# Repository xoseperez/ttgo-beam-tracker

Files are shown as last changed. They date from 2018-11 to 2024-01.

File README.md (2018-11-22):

# TTN Tracker

This is a LoRaWAN node based on the TTGO T-Beam development platform.
It uses a RFM95 by HopeRF and the MCCI LoRaWAN LMIC stack.
The sample code is configured to connect to The Things Network using EU frequency, but you can easily change that.






This repository contains:

* 3D model of the enclosure, both OpenSCAD and STL files.
* Sample code that sends GPS data compatible with [TTNMapper](http://ttnmapper.org).
* Javascript decoder code to decode payload

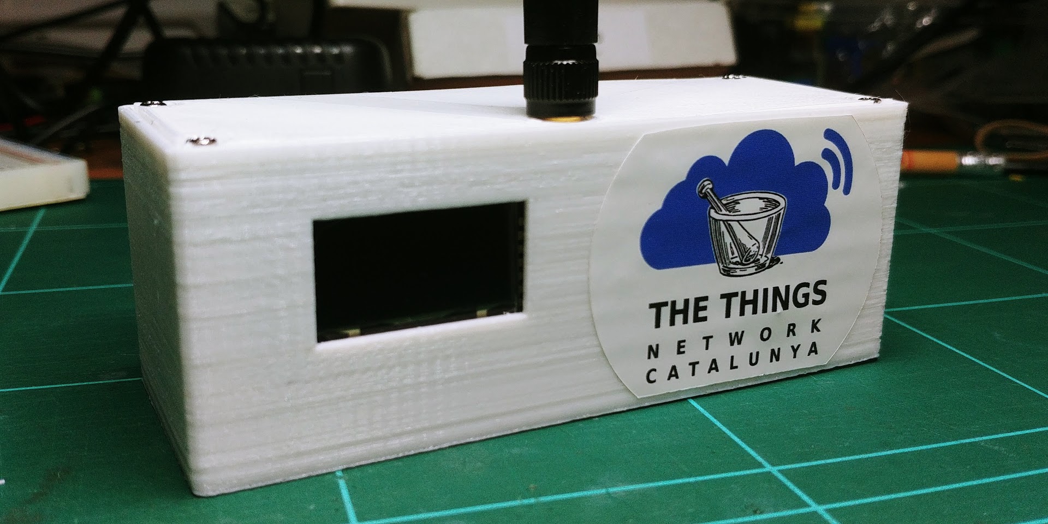
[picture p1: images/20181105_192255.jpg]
Device


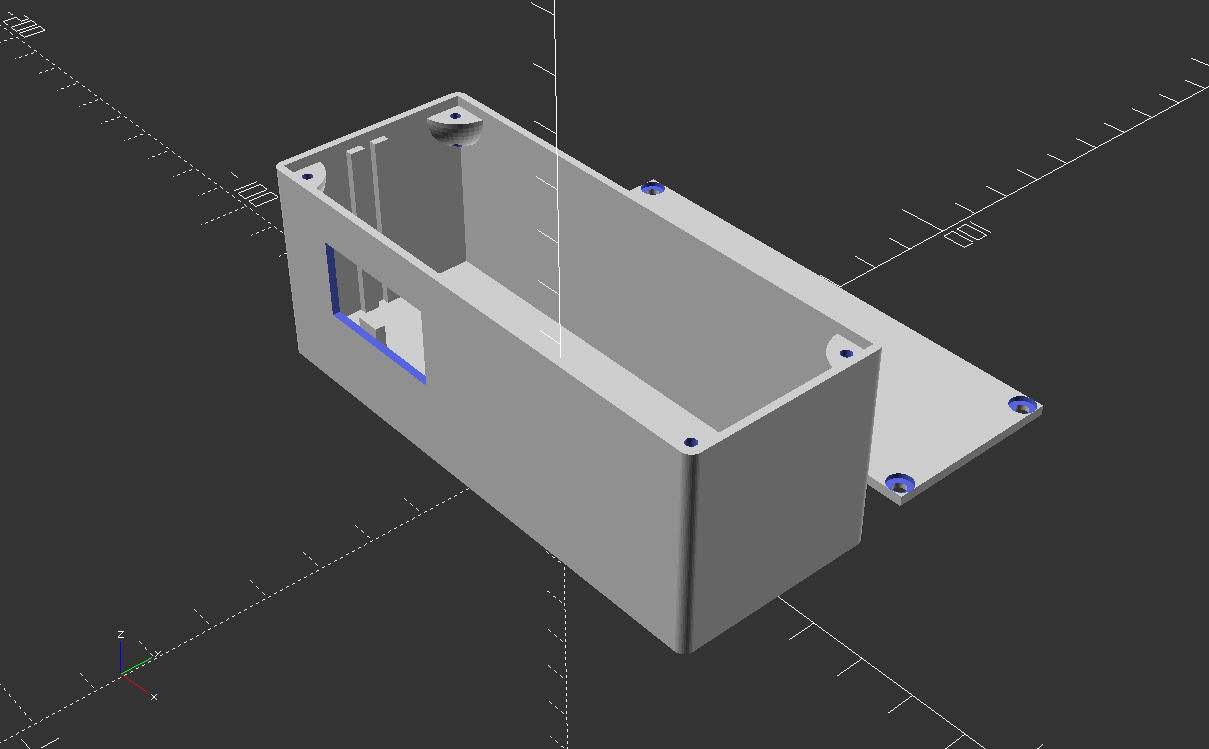
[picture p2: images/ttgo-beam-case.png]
Design


## License

Copyright (C) 2018 by Xose Pérez (@xoseperez)

This program is free software: you can redistribute it and/or modify
it under the terms of the GNU General Public License as published by
the Free Software Foundation, either version 3 of the License, or
(at your option) any later version.

This program is distributed in the hope that it will be useful,
but WITHOUT ANY WARRANTY; without even the implied warranty of
MERCHANTABILITY or FITNESS FOR A PARTICULAR PURPOSE.  See the
GNU General Public License for more details.

You should have received a copy of the GNU General Public License
along with this program.  If not, see <http://www.gnu.org/licenses/>.

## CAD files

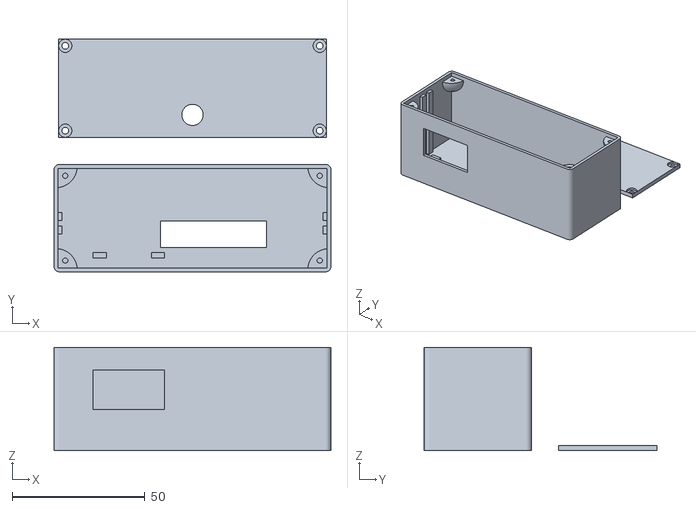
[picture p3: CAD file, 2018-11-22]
enclosure/ttgo-beam.stl
104.5 x 87.7 x 39.0

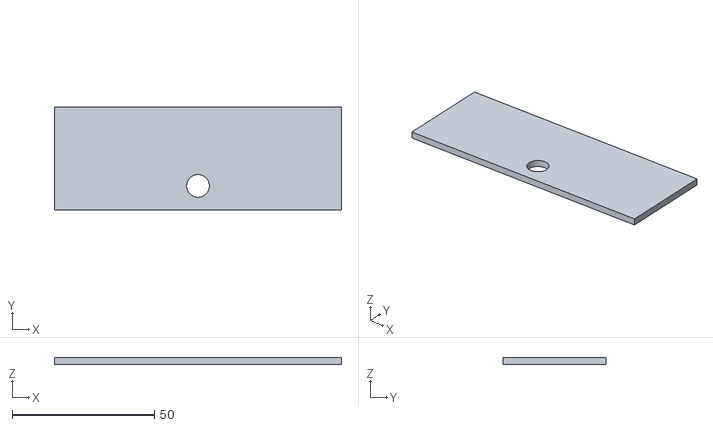
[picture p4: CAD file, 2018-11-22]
enclosure/ttgo-beam-lid.stl
101.0 x 36.3 x 2.50

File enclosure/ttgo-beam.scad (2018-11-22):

// -------------------------------------------------
// Settings
// -------------------------------------------------

$fn = 50;

// -------------------------------------------------
// Configuration
// -------------------------------------------------

device_width = 100.0;
device_depth = 36.0;
device_height = 34.0;
wall_thickness = 3.0;
board_thickness = 2.1;
device_front_depth = 16.0;
rack_depth = 3.0;
corner_radius = 8.0;
screw_length = 12.0;
screw_head = 2.5;
screw_offset = 3.5; // was 2.5
display_left = 12.5;
display_bottom = 12.5;
display_width = 27.0;
display_inner_width = 17.0;
display_height = 15.0;
display_guide = 4.0;
antenna_radius = 4.0;
antenna_y = -7;
xamfra = 2;

// -------------------------------------------------

board_y = -device_depth/2 + device_front_depth - board_thickness / 2;
box_width = device_width + wall_thickness;
box_depth = device_depth + wall_thickness;
box_height = device_height + wall_thickness;

// -------------------------------------------------
// Modules
// -------------------------------------------------

module base() {
    linear_extrude(wall_thickness) {
        difference() {
            minkowski() {
                square([box_width-2*xamfra, box_depth-2*xamfra], true);
                circle(xamfra, true);
            }
            translate([8, board_y-3]) square([40,10], true);
        }
    }
}

module lid() {
    difference() {
        linear_extrude(wall_thickness-1) {
            difference() {
                square([box_width-wall_thickness/2-0.5,box_depth-wall_thickness/2-0.5], true);
                translate([0, board_y + antenna_y]) circle(antenna_radius, true);
                translate([box_width/2-screw_offset, box_depth/2-screw_offset ]) circle(screw_head/2,true);
                translate([box_width/2-screw_offset, -box_depth/2+screw_offset ]) circle(screw_head/2,true);
                translate([-box_width/2+screw_offset, box_depth/2-screw_offset ]) circle(screw_head/2,true);
                translate([-box_width/2+screw_offset, -box_depth/2+screw_offset ]) circle(screw_head/2,true);
            }
        }
        translate([0,0,1]) linear_extrude(10) {
                translate([box_width/2-screw_offset, box_depth/2-screw_offset ]) circle(screw_head,true);
                translate([box_width/2-screw_offset, -box_depth/2+screw_offset ]) circle(screw_head,true);
                translate([-box_width/2+screw_offset, box_depth/2-screw_offset ]) circle(screw_head,true);
                translate([-box_width/2+screw_offset, -box_depth/2+screw_offset ]) circle(screw_head,true);

        }
    }
}

module walls() {
    difference() {
        union() {
            linear_extrude(box_height + wall_thickness - 1) {
                difference() {
                    minkowski() {
                        square([box_width+wall_thickness/2-2*xamfra,box_depth+wall_thickness/2-2*xamfra], true);
                        circle(xamfra, true);
                    }
                    square([box_width-wall_thickness/2,box_depth-wall_thickness/2], true);
                }
            }
            translate([
                -box_width/2+wall_thickness/2+display_left+display_width/2,
                -(box_depth-wall_thickness)/2+display_guide
            ]) linear_extrude(display_bottom) {
                difference() {
                    square([display_width, 2], true);
                    square([display_inner_width, 2], true);
                }
            }
        }
        translate([
            -box_width/2+wall_thickness/2+display_left+display_width/2,
            -(box_depth-wall_thickness)/2,
            display_bottom+display_height/2+wall_thickness
        ]) display();
    }
}

module rack() {
    linear_extrude(box_height) {
        translate([0,board_y+board_thickness/2]) 
            union() {
                translate([(box_width-wall_thickness)/2,
                    (board_thickness+rack_depth)/2]) {
                    square([rack_depth/2,rack_depth], true);
                }
                translate([(box_width-wall_thickness)/2,
                    -(board_thickness+rack_depth)/2]) {
                    square([rack_depth/2,rack_depth], true);
                }
                translate([-(box_width-wall_thickness)/2,
                    (board_thickness+rack_depth)/2]) {
                    square([rack_depth/2,rack_depth], true);
                }
                translate([-(box_width-wall_thickness)/2,
                    -(board_thickness+rack_depth)/2]) {
                    square([rack_depth/2,rack_depth], true);
                }
            }
    }
}

module corners() {
    union() {
        translate([-box_width/2,-box_depth/2,box_height]) corner();
        translate([box_width/2,-box_depth/2,box_height]) rotate([0,0,90]) corner();
        translate([box_width/2,box_depth/2,box_height]) rotate([0,0,180]) corner();
        translate([-box_width/2,box_depth/2,box_height]) rotate([0,0,270]) corner();
    }
}

module corner() {
    difference() {
        intersection() {
            sphere(corner_radius, true);
            translate([0,0,-corner_radius]) cube(corner_radius);
        }
        translate([screw_offset,screw_offset,-screw_length]) linear_extrude(screw_length) {
            circle([screw_head/2],true);
        }
    }
}

module display() {
    rotate([90,0,0])
        linear_extrude(wall_thickness)
            square([display_width, display_height], true);
}

module device() {
    rotate([90,0,0]) linear_extrude(1.6) square([device_width, device_height], true);
}

// -------------------------------------------------
// Entry points
// -------------------------------------------------

module full() {
    union() {
        base();
        walls();
        rack();
        corners();
    }
}

full();
//translate([0,0,box_height + 10]) lid();
translate([0,box_depth + 10,0]) lid();
//translate([0,board_y+wall_thickness/2,wall_thickness + device_height/2]) device();

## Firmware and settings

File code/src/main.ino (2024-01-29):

/*

Main module

Copyright (C) 2018-2019 by Xose Pérez <xose dot perez at gmail dot com>

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
*/

#include "configuration.h"
#include <rom/rtc.h>
#include <CayenneLPP.h>

// Cayenne buffer
CayenneLPP lpp(51);

// Message counter, stored in RTC memory, survives deep sleep
RTC_DATA_ATTR uint32_t count = 0;

// -----------------------------------------------------------------------------
// Application
// -----------------------------------------------------------------------------

void send() {

    /*
    
    Channel definition for trackers:

    CHANNEL 0: counter (digital_out_0)
    CHANNEL 1: gps (gps_1.altitude gps_1.latitude gps_1.longitude)
    CHANNEL 2: temperature (temperature_2)
    CHANNEL 3: accelerometer (accelerometer_3.x accelerometer_3.y accelerometer_3.z)
    CHANNEL 4: battery (analog_out_4) in volts
    CHANNEL 5: sats (digital_out_5)
    CHANNEL 6: hdop (analog_out_4)

    */

    char buffer[40];
    snprintf(buffer, sizeof(buffer), "Latitude: %10.6f\n", gps_latitude());
    screen_print(buffer);
    snprintf(buffer, sizeof(buffer), "Longitude: %10.6f\n", gps_longitude());
    screen_print(buffer);
    snprintf(buffer, sizeof(buffer), "Error: %4.2fm\n", gps_hdop());
    screen_print(buffer);

    lpp.reset();
    lpp.addDigitalOutput(0, count);
    if (gps_lock()) {
        lpp.addGPS(1, gps_latitude(), gps_longitude(), gps_altitude());
    } else {
        screen_print("No GPS lock yet\n");
    }
    //lpp.addAnalogOutput(4, battery());
    lpp.addDigitalOutput(5, gps_sats());
    lpp.addAnalogOutput(6, gps_hdop());

    #if LORAWAN_CONFIRMED_EVERY > 0
        bool confirmed = (count % LORAWAN_CONFIRMED_EVERY == 0);
    #else
        bool confirmed = false;
    #endif

    ttn_cnt(count);
    ttn_send(lpp.getBuffer(), lpp.getSize(), LORAWAN_PORT, confirmed);

    count++;

}

void sleep() {

    #if SLEEP_BETWEEN_MESSAGES

        if (gps_lock()) {

            // Show the going to sleep message on the screen
            char buffer[20];
            snprintf(buffer, sizeof(buffer), "Sleeping in %3.1fs\n", (MESSAGE_TO_SLEEP_DELAY / 1000.0));
            screen_print(buffer);

        }
    
    #endif

    // Wait for MESSAGE_TO_SLEEP_DELAY millis to sleep
    delay(MESSAGE_TO_SLEEP_DELAY);

    #if SLEEP_BETWEEN_MESSAGES

        if (gps_lock()) {
        
            // Turn off screen
            screen_off();

            // Set the user button to wake the board
            sleep_interrupt(BUTTON_PIN, LOW);

            // We sleep for the interval between messages minus the current millis
            // this way we distribute the messages evenly every SEND_INTERVAL millis
            uint32_t sleep_for = (millis() < SEND_INTERVAL) ? SEND_INTERVAL - millis() : SEND_INTERVAL;
            sleep_millis(sleep_for);
        
        }

    #endif

}

void callback(uint8_t message) {

    if (EV_JOINING == message) screen_print("Joining TTN...\n");
    if (EV_JOINED == message) screen_print("TTN joined!\n");
    if (EV_JOIN_FAILED == message) screen_print("TTN join failed\n");
    if (EV_REJOIN_FAILED == message) screen_print("TTN rejoin failed\n");
    if (EV_RESET == message) screen_print("Reset TTN connection\n");
    if (EV_LINK_DEAD == message) screen_print("TTN link dead\n");
    if (EV_ACK == message) screen_print("ACK received\n");
    if (EV_PENDING == message) screen_print("Message discarded\n");
    if (EV_QUEUED == message) screen_print("Message queued\n");

    if (EV_TXCOMPLETE == message) {
        screen_print("Message sent\n");
        sleep();
    }

    if (EV_RESPONSE == message) {

        screen_print("[TTN] Response: ");

        size_t len = ttn_response_len();
        uint8_t data[len];
        ttn_response(data, len);

        char buffer[6];
        for (uint8_t i=0; i<len; i++) {
            snprintf(buffer, sizeof(buffer), "%02X", data[i]);
            screen_print(buffer);
        }

        screen_print("\n");

    }

}

uint32_t get_count() {
    return count;
}

void setup() {

    // Debug
    #ifdef DEBUG_PORT
        DEBUG_PORT.begin(SERIAL_BAUD);
    #endif

    // Buttons & LED
    pinMode(BUTTON_PIN, INPUT_PULLUP);
    pinMode(LED_PIN, OUTPUT);

    // Hello
    DEBUG_MSG(APP_NAME " " APP_VERSION "\n");

    // Display
    screen_setup();

    // Init GPS
    gps_setup();

    // Show logo on first boot
    if (0 == count) {
        screen_print(APP_NAME " " APP_VERSION, 0, 0);
        screen_show_logo();
        screen_update();
        delay(LOGO_DELAY);
    }

    // TTN setup
    if (!ttn_setup()) {
        screen_print("[ERR] Radio module not found!\n");
        delay(MESSAGE_TO_SLEEP_DELAY);
        screen_off();
        sleep_forever();
    }

    ttn_register(callback);
    ttn_join();
    ttn_sf(LORAWAN_SF);
    ttn_adr(LORAWAN_ADR);

}

void loop() {

    gps_loop();
    ttn_loop();
    screen_loop();

    // Send every SEND_INTERVAL millis
    static uint32_t last = 0;
    if (0 == last || millis() - last > SEND_INTERVAL) {
        last = millis();
        send();
    }
    
}

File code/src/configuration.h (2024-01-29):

/*

TTGO-BEAM based TTN Tracker

Copyright (C) 2018-2019 by Xose Pérez <xose dot perez at gmail dot com>

This code requires LMIC library by Matthijs Kooijman
https://github.com/matthijskooijman/arduino-lmic

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
*/

#pragma once

#include <Arduino.h>
#include <lmic.h>

void ttn_register(void (*callback)(uint8_t message));

// -----------------------------------------------------------------------------
// Version
// -----------------------------------------------------------------------------

#define APP_NAME                "TTN TRACKER"
#define APP_VERSION             "0.1.3"

// -----------------------------------------------------------------------------
// Configuration
// -----------------------------------------------------------------------------

#define DEBUG_PORT              Serial      // Serial debug port
#define SERIAL_BAUD             115200      // Serial debug baud rate
#define SEND_INTERVAL           15000       // Sleep for these many millis
#define SLEEP_BETWEEN_MESSAGES  1           // Do sleep between messages
#define MESSAGE_TO_SLEEP_DELAY  500         // Time after message before going to sleep
#define LOGO_DELAY              3000        // Time to show logo on first boot
#define LORAWAN_PORT            1           // Port the messages will be sent to
#define LORAWAN_CONFIRMED_EVERY 0           // Send confirmed message every these many messages (0 means never)
#define LORAWAN_SF              DR_SF7      // Spreading factor
#define LORAWAN_ADR             0           // Enable ADR
#define GPS_WAIT_FOR_LOCK       10000       // Wait 5s after every boot for GPS lock

// -----------------------------------------------------------------------------
// DEBUG
// -----------------------------------------------------------------------------

#ifdef DEBUG_PORT
#define DEBUG_MSG(...) DEBUG_PORT.printf( __VA_ARGS__ )
#else
#define DEBUG_MSG(...)
#endif

// -----------------------------------------------------------------------------
// Custom messages
// -----------------------------------------------------------------------------

#define EV_QUEUED       100
#define EV_PENDING      101
#define EV_ACK          102
#define EV_RESPONSE     103

// -----------------------------------------------------------------------------
// General
// -----------------------------------------------------------------------------

#define BUTTON_PIN      39
#define LED_PIN         14

// -----------------------------------------------------------------------------
// OLED
// -----------------------------------------------------------------------------

#define OLED_ADDRESS    0x3C
#define OLED_SDA        21
#define OLED_SCL        22

// -----------------------------------------------------------------------------
// GPS
// -----------------------------------------------------------------------------

#define GPS_SERIAL_NUM  2
#define GPS_RX_PIN      12
#define GPS_TX_PIN      15
#define GPS_BAUDRATE    9600

// -----------------------------------------------------------------------------
// LoRa SPI
// -----------------------------------------------------------------------------

#define SCK_GPIO        5
#define MISO_GPIO       19
#define MOSI_GPIO       27
#define NSS_GPIO        18
#define RESET_GPIO      23
#define DIO0_GPIO       26
#define DIO1_GPIO       33
#define DIO2_GPIO       32

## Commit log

2019-08-13 Set message to sleep delay to 500ms
    [configuration.h]
2019-08-13 Update copyright notice
    [configuration.h]
2019-09-03 Update javascript decoder to support frames with no LUA_COMPATIBILITY_MODE (default)
2019-11-18 Fixed signature of the ttn_cnt method to allow unsigned long values
    [ttn.ino]
2021-02-07 Moved to CayenneLPP frame
    [configuration.h]
2024-01-29 Update dependencies
    [configuration.h]
